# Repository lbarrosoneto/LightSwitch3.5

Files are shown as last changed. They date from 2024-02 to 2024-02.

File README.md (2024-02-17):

# LightSwitch3.5
This is a ESP32 Smart Light Switch with 3.5 Inch TFT Display, compatible with OpenHASP https://www.openhasp.com

The light switch is available in 2 configurations and  replaces standard mechanical switches for single / double gang.

## Vertical single-gang 
  


## Horizontal Double Gang
  


# Disclaimer
---
THIS PROJECT INVOLVES MONKEYING WITH HIGH VOLTAGE AND YOU COULD KILL YOURSELF 
AND/OR SET YOUR HOUSE ON FIRE

The end result is a thing that connects to live voltage and will be placed into 
your wall for years to come. It will not carry any sort of UL/CE/etc certification. 
Proceed with extreme caution.

EXCLUSION AND LIMITATION OF LIABILITY 
The developer shall, to
the maximum extent permitted by law, have no liability for
direct, indirect, special, incidental, consequential, exemplary,
punitive or other damages of any character including, without
limitation, procurement of substitute goods or services, loss of
use, data or profits, or business interruption, however caused
and on any theory of contract, warranty, tort (including
negligence), product liability or otherwise, arising in any way
in relation to the Covered Source, modified Covered Source
and/or the Making or Conveyance of a Product, even if advised of
the possibility of such damages, and You shall hold the
developer free and harmless from any liability, costs,
damages, fees and expenses, including claims by third parties,
in relation to such use.
      
---

# Hardware Design

2 PCBs compose the hardware design, that is available from https://github.com/lbarrosoneto/LightSwitch3.5/tree/main/HWDesign

## ESP32 Display Controller

  

## Relay and Power Board
  
  

# 3D Print Files
3D print design files for single and double gang versions is available from https://github.com/lbarrosoneto/LightSwitch3.5/tree/main/3DPrintCase

# Programming the LightSwitch3.5
Follow the instructions from https://www.openhasp.com/0.7.0/firmware/compiling/local/#native-windows-build

Lightswitch3.5 is compatible with the esp32-touchdown https://github.com/DustinWatts/esp32-touchdown



The Relays are connected to IO12 and IO13, so, those ports need to be configured "Pin Output" in the Light Switch Web Interface (Under Configuration->GPIO Settings): 



The hardware design is copyright (c) Luiz Oliveira Neto <lboneto@gmail.com> and licensed under [CERN Open Hardware Licence Version 2 - Strongly Reciprocal](https://github.com/lbarrosoneto/LightSwitch3.5)

The 3D Prints are copyright (c) Luiz Oliveira Neto <lboneto@gmail.com>  and licensed Creative Commons share alike.

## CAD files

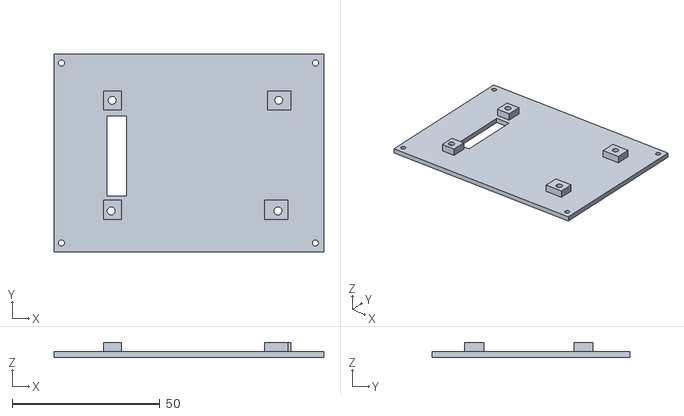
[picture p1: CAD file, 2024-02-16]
3DPrintCase/DualGangUSA/3.5DualLCD_Switch_back_plate.stl
91.5 x 67.0 x 5.00

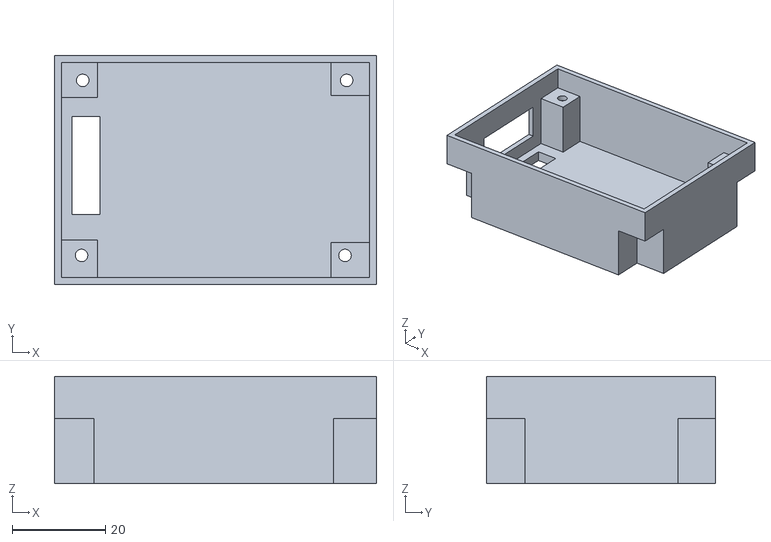
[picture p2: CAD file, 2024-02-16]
3DPrintCase/SingleGangUSA/3.5 Single_back_cover.stl
69.0 x 49.0 x 23.0

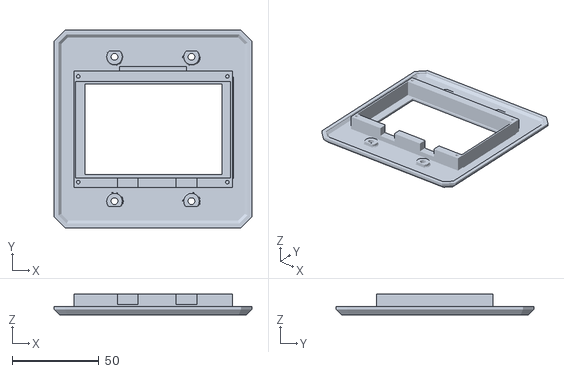
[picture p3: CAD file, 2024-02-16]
3DPrintCase/DualGangUSA/3.5DualLCD_Switch_front_bezel.stl
114.3 x 114.3 x 12.0

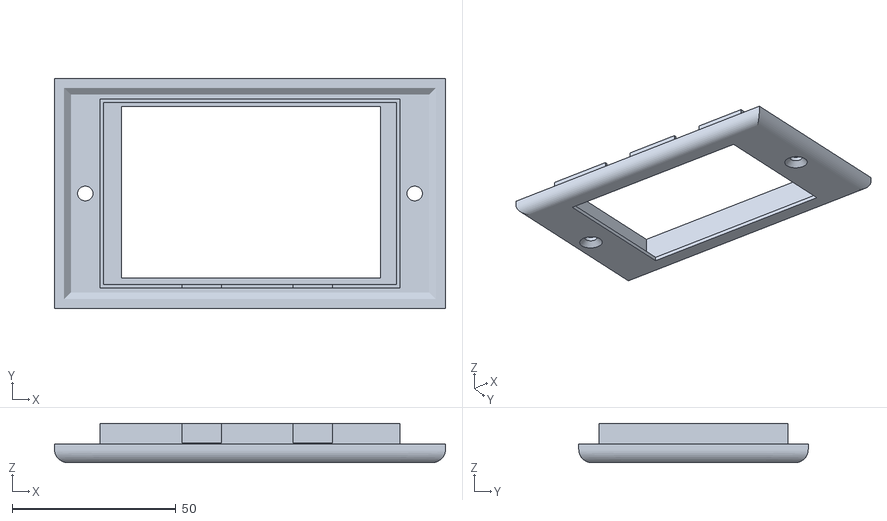
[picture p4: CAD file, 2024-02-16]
3DPrintCase/SingleGangUSA/3.5 Single_front_bezel.stl
119.2 x 70.0 x 12.0

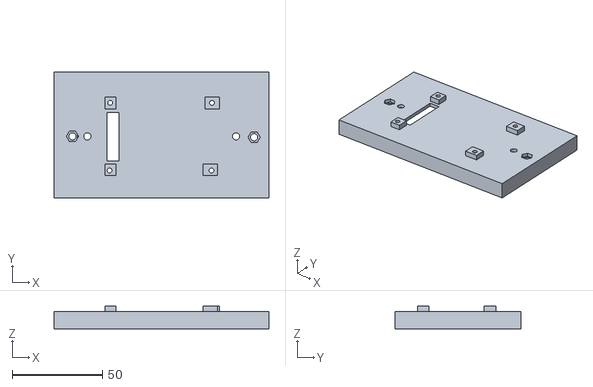
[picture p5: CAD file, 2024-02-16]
3DPrintCase/SingleGangUSA/3.5 Single_bezel_back_plate.stl
119.2 x 70.0 x 12.5

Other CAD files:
3DPrintCase/DualGangUSA/3.5DualLCD_Switch_back_cover.stl

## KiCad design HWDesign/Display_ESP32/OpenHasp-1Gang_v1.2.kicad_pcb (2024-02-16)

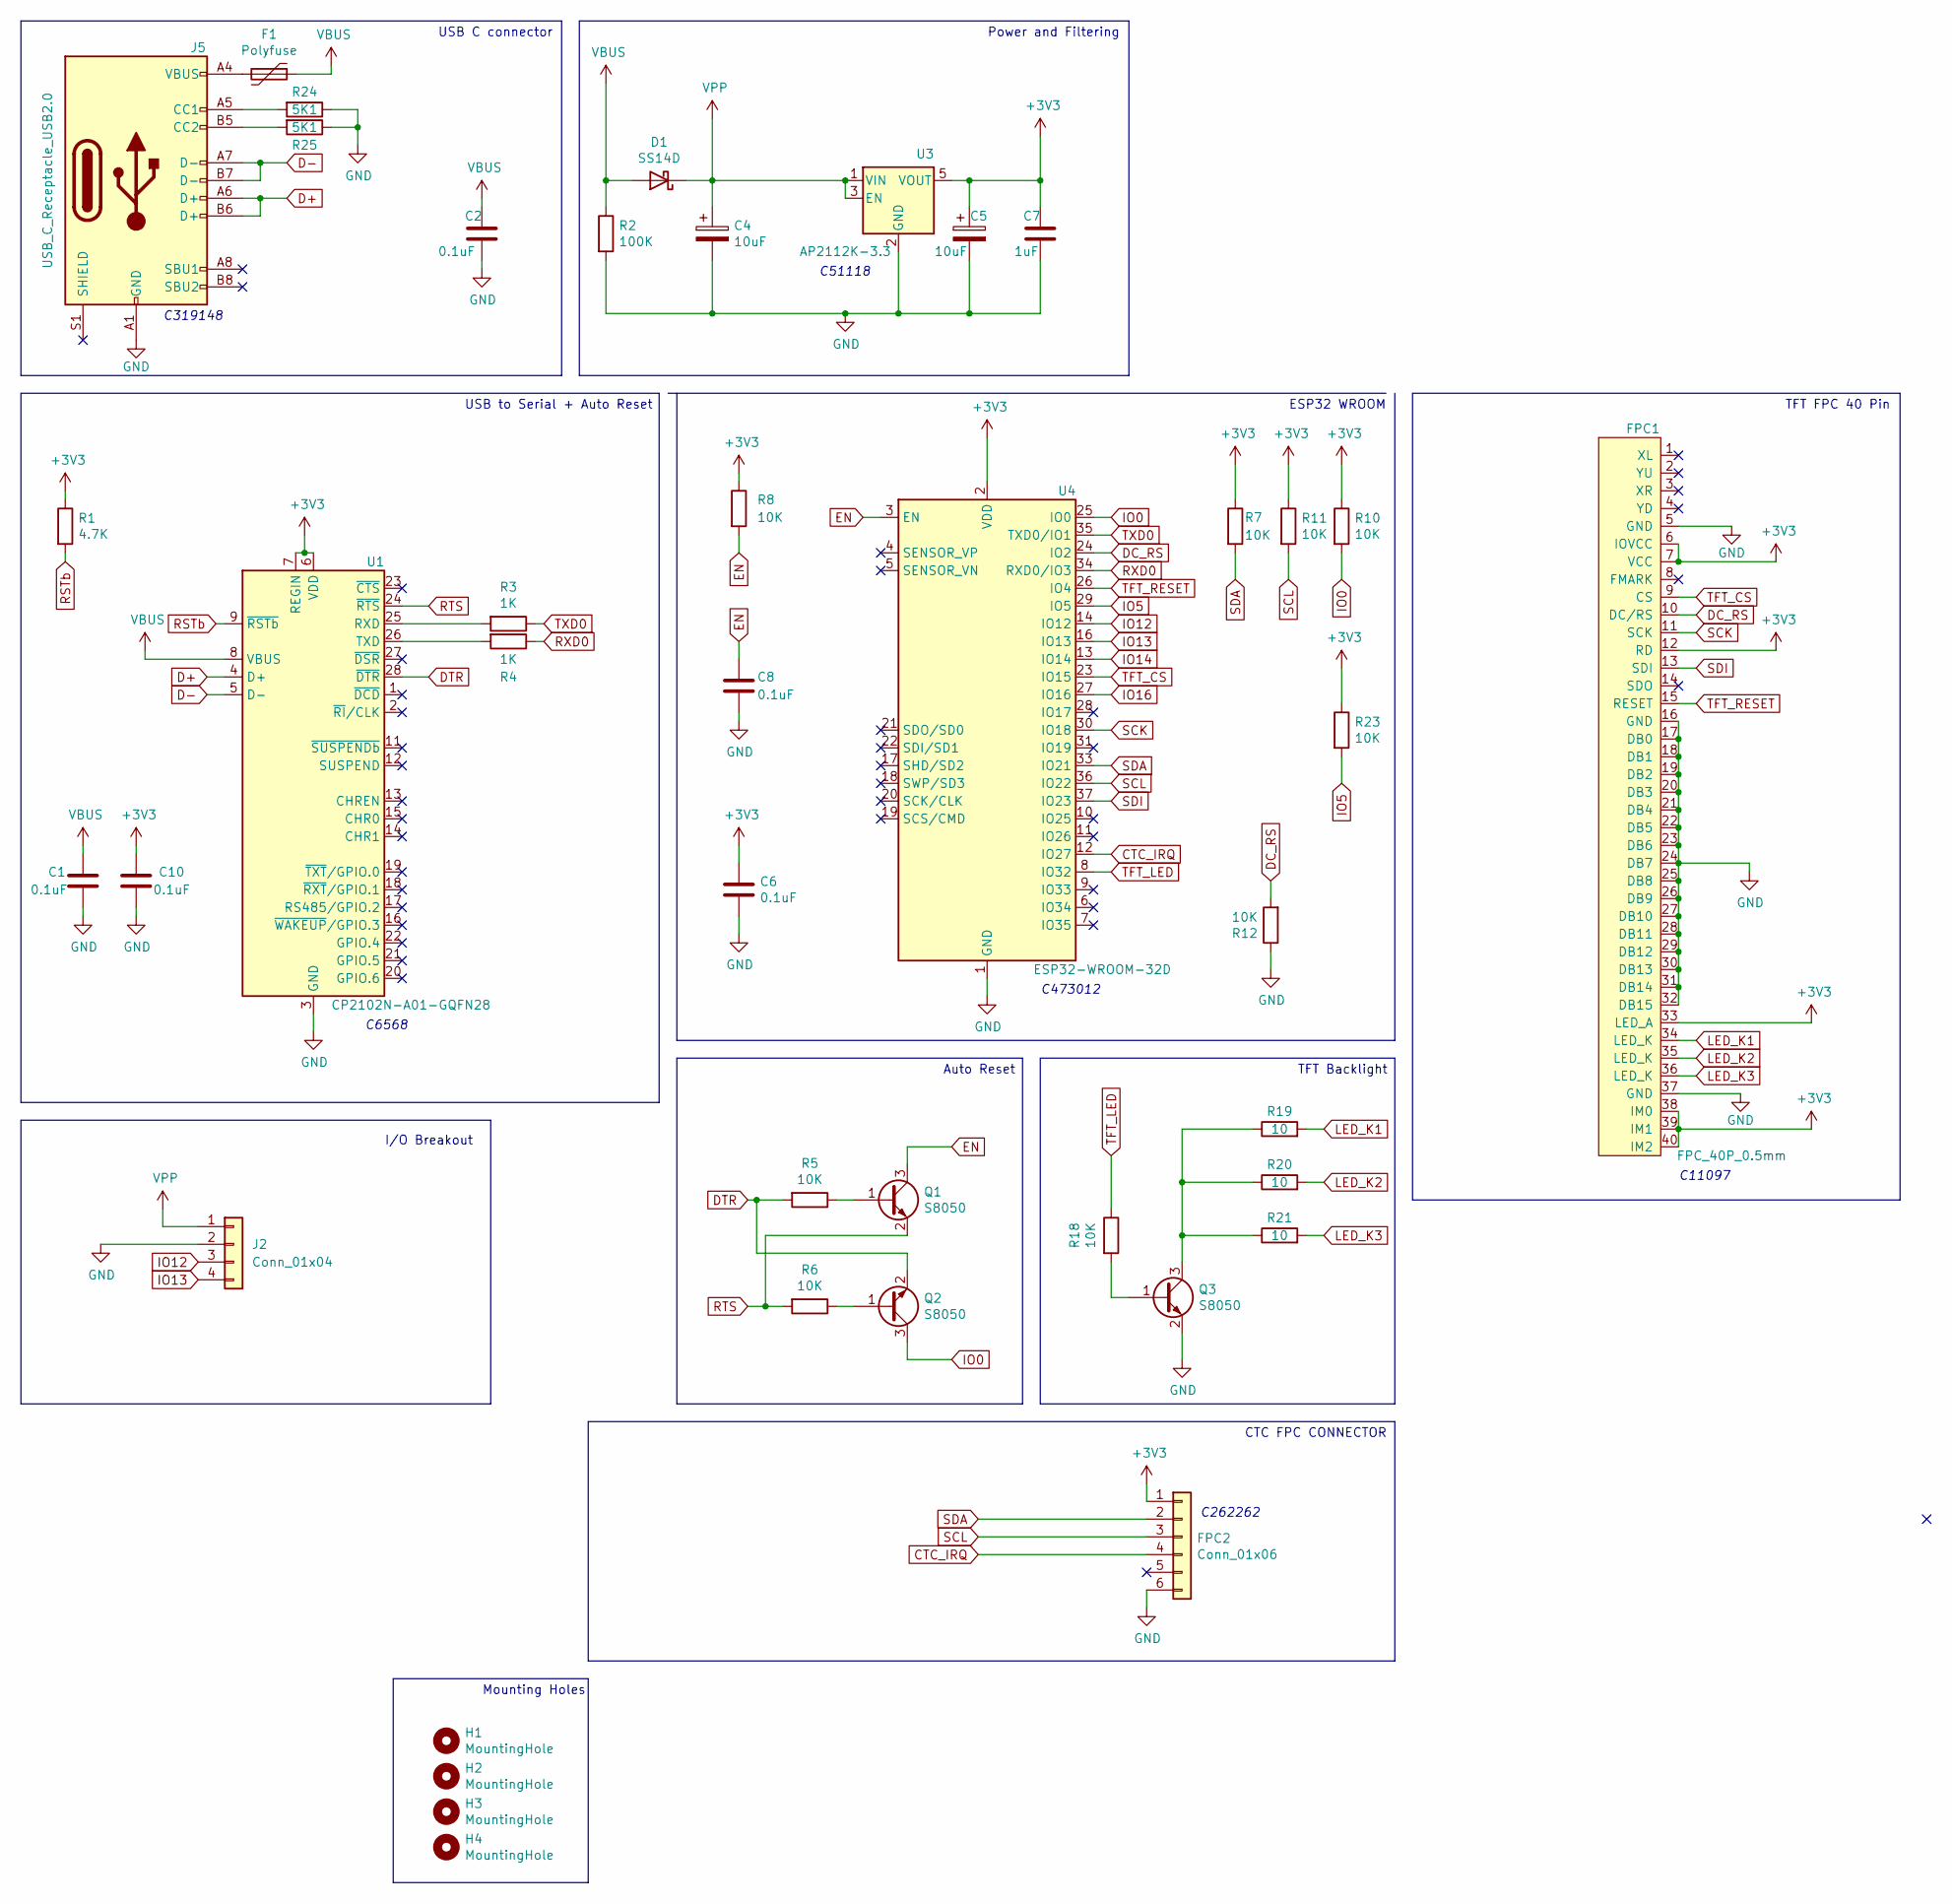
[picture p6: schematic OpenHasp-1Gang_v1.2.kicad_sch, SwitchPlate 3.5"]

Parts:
C1, C2, C6, C8, C10: 0.1uF; C_0603_1608Metric; LCSC C1591
C4, C5: 10uF; CP_EIA-3216-18_Kemet-A; LCSC C7177
C7: 1uF; C_0603_1608Metric; LCSC C1592
D1: SS14D; D_SMA; LCSC C83912
F1: Polyfuse; Fuse_0805_2012Metric; LCSC C151146
FPC1: FPC_40P_0.5mm; Hirose_FH12-40S-0.5SH_1x40-1MP_P0.50mm_Horizontal_flipped_c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; LCSC C11097
FPC2: Conn_01x06; Hirose_FH12-6S-0.5SH_1x06-1MP_P0.50mm_Horizontal; LCSC C262262
H1, H2, H3, H4: MountingHole; MountingHole_2.5mm_Pad_Via
J2: Conn_01x04; JST_PH_S4B-PH-SM4-TB_1x04-1MP_P2.00mm_Horizontal
J5: USB_C_Receptacle_USB2.0; USB_C_Receptacle_XKB_U262-16XN-4BVC11; LCSC C319148
Q1, Q2, Q3: S8050; SOT-23; LCSC C402279
R1: 4.7K; R_0603_1608Metric; LCSC C88615
R2: 100K; R_0603_1608Metric; LCSC C73806
R3, R4: 1K; R_0603_1608Metric; LCSC C73797
R5, R6, R7, R8, R10, R11, R12, R18, R23: 10K; R_0603_1608Metric; LCSC C99198
R19, R20, R21: 10; R_0603_1608Metric; LCSC C176153
R24, R25: 5K1; R_0603_1608Metric; LCSC C73801
U1: CP2102N-A01-GQFN28; QFN-28-1EP_5x5mm_P0.5mm_EP3.35x3.35mm; LCSC C6568
U3: AP2112K-3.3; SOT-23-5; LCSC C150742
U4: ESP32-WROOM-32D; ESP32-WROOM-32; LCSC C473012

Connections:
+3V3: C5.1, C6.1, C7.1, C10.1, FPC1.6 (IOVCC), FPC1.7 (VCC), FPC1.12 (RD), FPC1.33 (LED_A), FPC1.38 (IM0), FPC1.39 (IM1), FPC1.40 (IM2), FPC2.1, R1.1, R7.1, R8.1, R10.1, R11.1, R23.1, U1.6 (VDD), U1.7 (REGIN), U3.5 (VOUT), U4.2 (VDD)
CTC_IRQ: FPC2.4, U4.12 (IO27)
D+: J5.A6 (D+), J5.B6 (D+), U1.4 (D+)
D-: J5.A7 (D-), J5.B7 (D-), U1.5 (D-)
DC_RS: FPC1.10 (DC/RS), R12.2, U4.24 (IO2)
DTR: Q2.2 (B), R5.2, U1.28 (~DTR)
EN: C8.1, Q1.3 (C), R8.2, U4.3 (EN)
GND: C1.2, C2.2, C4.2, C5.2, C6.2, C7.2, C8.2, C10.2, FPC1.5 (GND), FPC1.16 (GND), FPC1.17 (DB0), FPC1.18 (DB1), FPC1.19 (DB2), FPC1.20 (DB3), FPC1.21 (DB4), FPC1.22 (DB5), FPC1.23 (DB6), FPC1.24 (DB7), FPC1.25 (DB8), FPC1.26 (DB9), FPC1.27 (DB10), FPC1.28 (DB11), FPC1.29 (DB12), FPC1.30 (DB13), FPC1.31 (DB14), FPC1.32 (DB15), FPC1.37 (GND), FPC2.6, J2.2, J5.A1 (GND), J5.A12 (GND), J5.B1 (GND), J5.B12 (GND), Q3.2 (B), R2.2, R12.1, R24.1, R25.1, U1.3 (GND), U1.29 (GND), U3.2 (GND), U4.1 (GND), U4.15 (GND), U4.38 (GND), U4.39 (GND)
IO0: Q2.3 (C), R10.2, U4.25 (IO0)
IO5: R23.2, U4.29 (IO5)
IO12: J2.3, U4.14 (IO12)
IO13: J2.4, U4.16 (IO13)
IO14: U4.13 (IO14)
IO16: U4.27 (IO16)
LED_K1: FPC1.34 (LED_K), R19.2
LED_K2: FPC1.35 (LED_K), R20.2
LED_K3: FPC1.36 (LED_K), R21.2
unnamed: F1.2, J5.A4 (VBUS), J5.A9 (VBUS), J5.B4 (VBUS), J5.B9 (VBUS)
unnamed: J5.A5 (CC1), R24.2
unnamed: J5.B5 (CC2), R25.2
unnamed: Q1.1 (E), R5.1
unnamed: Q2.1 (E), R6.1
unnamed: Q3.1 (E), R18.2
unnamed: Q3.3 (C), R19.1, R20.1, R21.1
unnamed: R3.2, U1.25 (RXD)
unnamed: R4.2, U1.26 (TXD)
RSTb: R1.2, U1.9 (~RSTb)
RTS: Q1.2 (B), R6.2, U1.24 (~RTS)
RXD0: R4.1, U4.34 (RXD0/IO3)
SCK: FPC1.11 (SCK), U4.30 (IO18)
SCL: FPC2.3, R11.2, U4.36 (IO22)
SDA: FPC2.2, R7.2, U4.33 (IO21)
SDI: FPC1.13 (SDI), U4.37 (IO23)
TFT_CS: FPC1.9 (CS), U4.23 (IO15)
TFT_LED: R18.1, U4.8 (IO32)
TFT_RESET: FPC1.15 (RESET), U4.26 (IO4)
TXD0: R3.1, U4.35 (TXD0/IO1)
VBUS: C1.1, C2.1, D1.2 (A), F1.1, R2.1, U1.8 (VBUS)
VPP: C4.1, D1.1 (K), J2.1, U3.1 (VIN), U3.3 (EN)

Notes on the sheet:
I/O Breakout
C262262
USB to Serial + Auto Reset
C11097
C473012
CTC FPC CONNECTOR
TFT Backlight
C51118
TFT FPC 40 Pin
Mounting Holes
USB C connector
Power and Filtering
Auto Reset
ESP32 WROOM
C6568
C319148

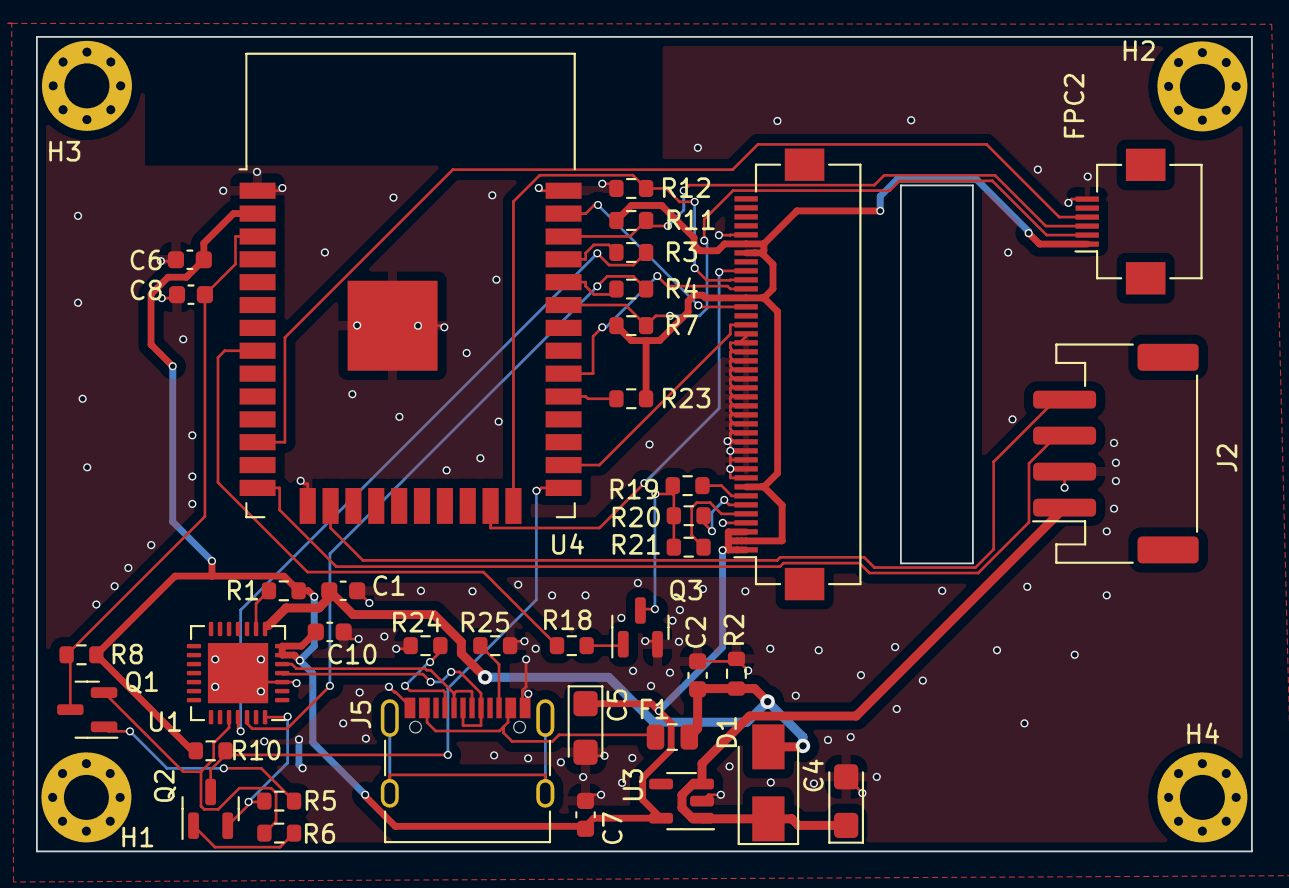
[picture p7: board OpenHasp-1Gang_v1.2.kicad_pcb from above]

Board: 2 copper layers, 67.5 x 45.2 mm, 42 parts (0 on the bottom side), 37 nets.

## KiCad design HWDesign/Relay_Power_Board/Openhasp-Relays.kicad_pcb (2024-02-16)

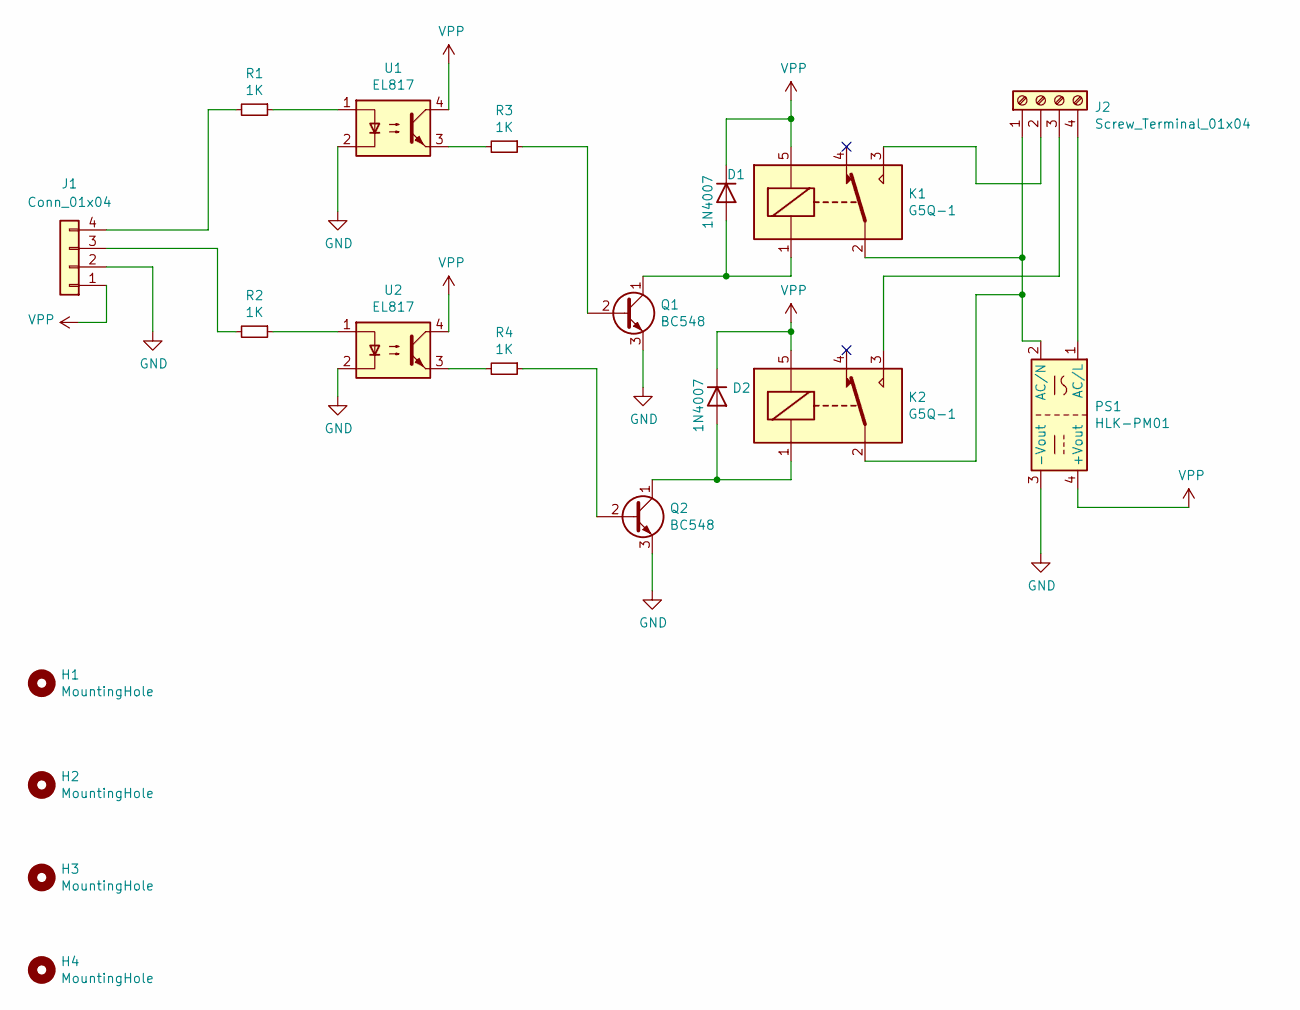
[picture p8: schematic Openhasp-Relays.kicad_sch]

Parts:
D1, D2: 1N4007; D_DO-41_SOD81_P10.16mm_Horizontal
H1, H2, H3, H4: MountingHole; MountingHole_2.2mm_M2_Pad_Via
J1: Conn_01x04; PinSocket_1x04_P2.54mm_Vertical
J2: Screw_Terminal_01x04; TE_MATE-N-LOK_350211-1_1x04_P5.08mm_Vertical
K1, K2: G5Q-1; Relay_SPDT_Omron-G5Q-1
PS1: HLK-PM01; Converter_ACDC_HiLink_HLK-PMxx
Q1, Q2: BC548; TO-92_Inline
R1, R2, R3, R4: 1K; R_Axial_DIN0204_L3.6mm_D1.6mm_P2.54mm_Vertical
U1, U2: EL817; DIP-4_W7.62mm

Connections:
GND: J1.2, PS1.3 (-Vout), Q1.3 (E), Q2.3 (E), U1.2, U2.2
unnamed: D1.2 (A), K1.1, Q1.1 (C)
unnamed: D2.2 (A), K2.1, Q2.1 (C)
unnamed: J1.3, R2.2
unnamed: J1.4, R1.2
unnamed: J2.1, K1.2, K2.2, PS1.2 (AC/N)
unnamed: J2.2, K1.3
unnamed: J2.3, K2.3
unnamed: J2.4, PS1.1 (AC/L)
unnamed: Q1.2 (B), R3.1
unnamed: Q2.2 (B), R4.1
unnamed: R1.1, U1.1
unnamed: R2.1, U2.1
unnamed: R3.2, U1.3
unnamed: R4.2, U2.3
VPP: D1.1 (K), D2.1 (K), J1.1, K1.5, K2.5, PS1.4 (+Vout), U1.4, U2.4

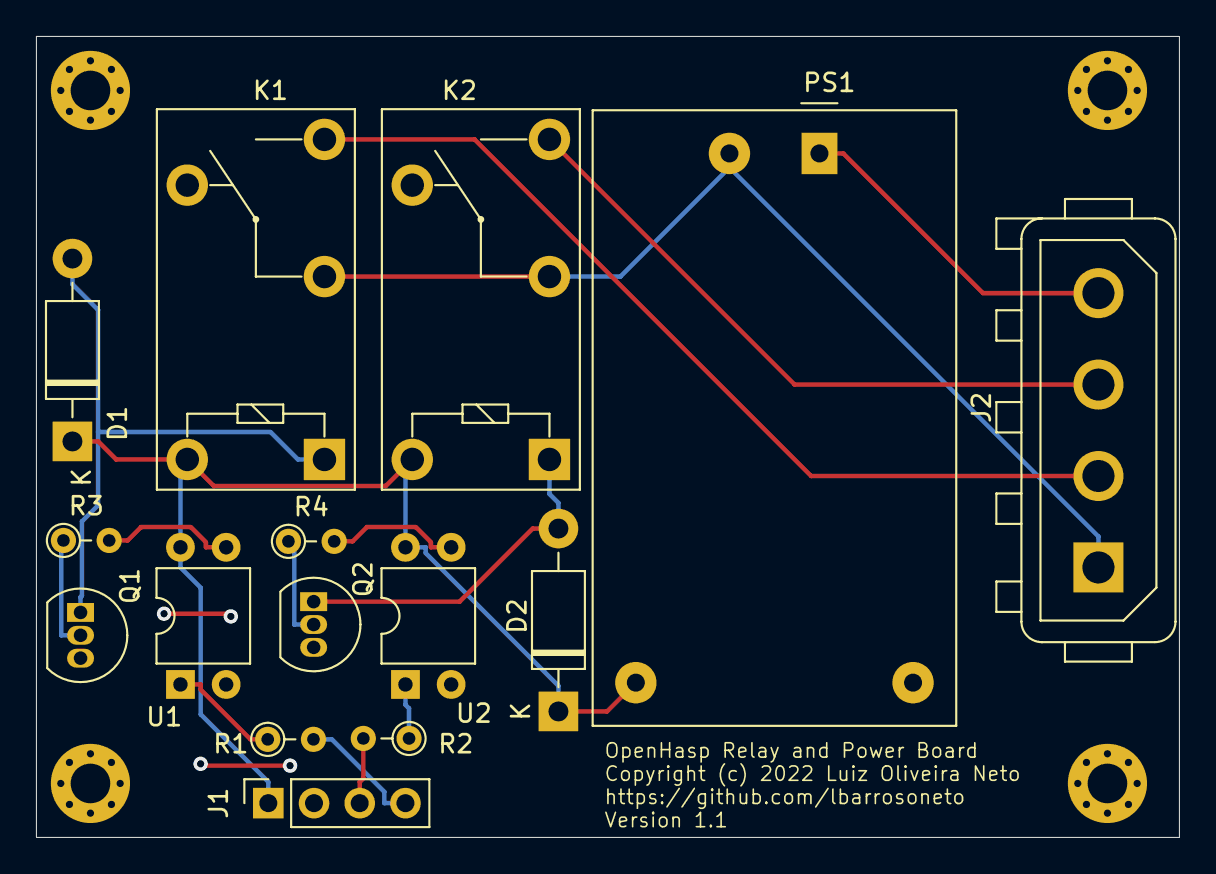
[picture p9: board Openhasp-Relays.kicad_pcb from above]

Board: 2 copper layers, 63.5 x 44.5 mm, 19 parts (0 on the bottom side), 16 nets.

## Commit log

2024-02-16 Initial Versions
    [3.5 Single_back_cover.stl, 3.5 Single_bezel_back_plate.stl, 3.5 Single_front_bezel.stl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]
2024-02-16 Adding License, COPYING and Relay board design
    [Openhasp-Relays.kicad_pcb, Openhasp-Relays.kicad_sch]
2024-02-16 Adding gerber/libraryfiles
    [OpenHasp-1Gang-B_Cu.gbr, OpenHasp-1Gang-B_Mask.gbr, OpenHasp-1Gang-B_Paste.gbr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]
2024-02-17 Adding more detailed Readme.md
    Readme.md is being updated to include:
    - Pictures
    - Hardware design details
    - 3D Print details
2024-02-17 Add LICENSE to 3D PRINTS

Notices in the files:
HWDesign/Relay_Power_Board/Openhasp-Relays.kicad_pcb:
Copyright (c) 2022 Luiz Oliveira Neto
